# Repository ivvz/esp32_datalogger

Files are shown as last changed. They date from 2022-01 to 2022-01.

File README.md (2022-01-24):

# ESP32 temperature datalogger

ESP32 based type k thermocouple temperature data logger

## Devices

- ESP32 lolin lite board
- OLED Screen SSD1306
- RTC Module DS3231
- Microsd moodule
- Max6675 module
- MT3608 boost dc-dc module
- Two push buttons

## Pinout

### Microsd
- MISO  --- Pin 19
- MOSI --- Pin 23
- SCK --- Pin 18
- CS --- Pin 5
- VCC --- MT3608 VOUT Pin 
- GND --- GND 

### SSD1306 (I2C)
- SCL -- Pin 32
- SDA --- Pin 33
- VCC --- MT3608 VOUT Pin                                                 
- GND --- GND     

### RTC DS3131 (I2C)
- SCL -- Pin 32                                                           
- SDA --- Pin 33 
- VCC --- MT3608 VOUT Pin                                                 
- GND --- GND 

### Thermocouple modules (MAX6675)
- DO (MISO) --- Pin 23                                                    - SCK --- Pin 4                                                          
- CS1 --- Pin 16
- CS2 --- Pin 15  
- CS3 --- Pin 13  
- VCC --- MT3608 VOUT Pin                                                 
- GND --- GND

# Schematics

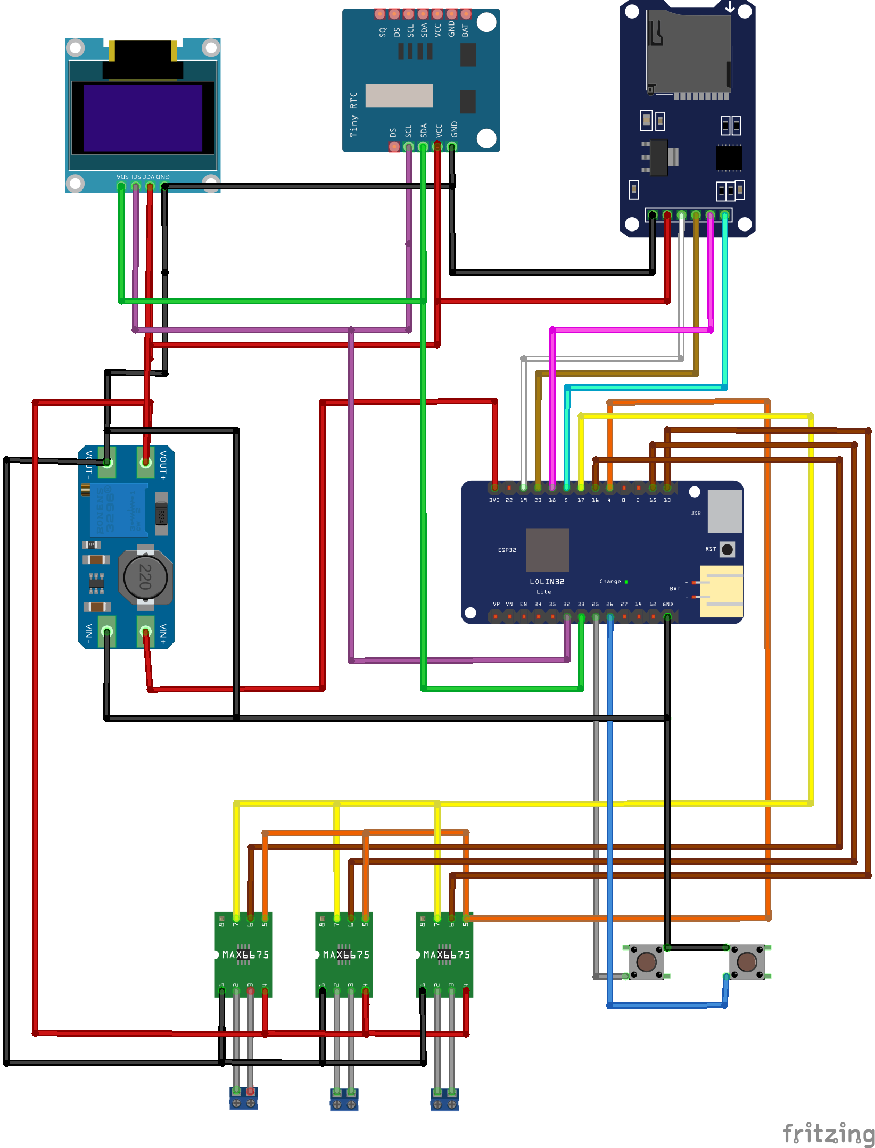
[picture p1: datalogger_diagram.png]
schematics


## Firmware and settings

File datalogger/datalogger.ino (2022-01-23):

#include "FS.h"
#include "SD.h"
#include "max6675.h"
#include <RTClib.h>
#include <SPI.h>
#include <Wire.h>
#include <Adafruit_GFX.h>
#include <Adafruit_SSD1306.h>



int boton_inicio = 25;
int boton_cierre = 26;
int estado_anterior_boton_inicio;
int estado_anterior_boton_final;
unsigned long tiempo_lectura = 10000; // intervalo de lectura general (sin ejecutar funcion de registro de datos)
unsigned long tiempo_sin_registro;
unsigned long tiempoEsperaLog = 0;

int thermoDO = 17;
int thermoCLK = 4;
int thermoCS1 = 16;
int thermoCS2 = 15;
int thermoCS3 = 13;

RTC_DS3231 rtc;     // crea objeto del tipo RTC_DS3231

MAX6675 termopar1(thermoCLK, thermoCS1, thermoDO);
MAX6675 termopar2(thermoCLK, thermoCS2, thermoDO);
MAX6675 termopar3(thermoCLK, thermoCS3, thermoDO);

#define SCREEN_WIDTH 128 // OLED display width, in pixels
#define SCREEN_HEIGHT 64 // OLED display height, in pixels

// Declaration for an SSD1306 display connected to I2C (SDA, SCL pins)
#define OLED_RESET     -1 // Reset pin # (or -1 if sharing Arduino reset pin)
Adafruit_SSD1306 display(SCREEN_WIDTH, SCREEN_HEIGHT, &Wire, OLED_RESET);
 
 
void setup(){
  Wire.begin(33, 32);
  Serial.begin(115200);
  delay(2000);

  //define los botones
  pinMode(boton_inicio, INPUT_PULLUP);
  pinMode(boton_cierre, INPUT_PULLUP);
  digitalWrite(boton_inicio, HIGH);
  digitalWrite(boton_inicio, HIGH);
  estado_anterior_boton_inicio = digitalRead(boton_inicio);
  estado_anterior_boton_final = digitalRead(boton_cierre);
  
  checkOLED();
  checkClock();
  //rtc.adjust(DateTime(__DATE__, __TIME__));  // funcion que permite establecer fecha y horario
             //al momento de la compilacion. Comentar esta linea
  checkSD();
 
}

void loop(){
  String hora;
  unsigned long displayTermoTime;
  unsigned long displayHourTime;
  if(millis() - tiempo_sin_registro >= tiempo_lectura){
     hora = getTime();
     Serial.println(hora + " Termopar 1 = " + String(termopar1.readCelsius()) + " C");
     Serial.println(hora + " Termopar 2 = " + String(termopar2.readCelsius()) + " C");
     Serial.println(hora + " Termopar 3 = " + String(termopar3.readCelsius()) + " C\n");
     showHour(0);
     delay(2000);
     displayHourTime = millis();
     if(millis() - displayHourTime <= 5000){
     displayTermoparData(0);
     displayHourTime = millis();
     }
     tiempo_sin_registro = millis();  
    }

  int estado_actual_boton_inicio = digitalRead(boton_inicio);
  int estado_actual_boton_final = digitalRead(boton_cierre);

  if (estado_actual_boton_inicio == LOW && estado_anterior_boton_inicio == HIGH ) {
      String dataString;
      String hourFile = getNameDate();
      String nombre;
      nombre += "/" + hourFile + ".csv";
      Serial.println("Nombre del archivo: " + nombre);
      Serial.println("Escribiendo datos");
      display.clearDisplay();
      display.setTextSize(2);
      display.setCursor(0,20);            
      display.print("CREANDO");
      display.setTextSize(2);  
      display.setCursor(20,40);            
      display.print("ARCHIVO");
      display.display();
      createFile(nombre);
      delay(5000);
     
     
    while(estado_actual_boton_final == HIGH){
      if(millis() - tiempoEsperaLog >= tiempo_lectura){
      dataString = createString();
      appendTempString(dataString,nombre);
      Serial.println(dataString);
      showHour(1);
      delay(2000);
      displayTermoparData(1);
      tiempoEsperaLog = millis();
      }
      estado_actual_boton_final = digitalRead(boton_cierre);
      }
      Serial.println("cerrando archivo....");
      Serial.println("se cerro el archivo.......\nvolviendo a la lectura");
      display.clearDisplay();
      display.setTextSize(2);
      display.setCursor(0,20);            
      display.print("GUARDANDO");
      display.setTextSize(2);  
      display.setCursor(20,40);            
      display.print("ARCHIVO");
      display.display();
      delay(5000);
  }
 
}



String createString(){
  // crea el string para csv con las temperaturas
    String dataString = "";
    String hora = getTime();
    unsigned long tiempo = millis();
    float lectura1 = termopar1.readCelsius();
    float lectura2 = termopar2.readCelsius();
    float lectura3 = termopar3.readCelsius();
    dataString += hora + ",";
    dataString += String(tiempo);
    dataString += ",";
    dataString += String(lectura1);
    dataString += ",";
    dataString += String(lectura2);
    dataString += ",";
    dataString += String(lectura3) + "\n";

  return dataString;
}


void createFile(String fileName){
  String header = ("hora,tiempo,termopar 1,termopar 2,termopar 3\n");
  writeFile(SD, fileName, header);
}

void appendTempString(String dataString, String fileName){
  appendFile(SD, fileName, dataString);
}

void checkSD(){
    display.clearDisplay();
    display.setTextSize(2);            
    display.setTextColor(WHITE);        
    display.setCursor(2,20);            
    display.println("REVISANDO  MICRO SD!");
    display.display();
    delay(2000);
    display.clearDisplay();
   
    if(!SD.begin(5)){
    Serial.println("Card Mount Failed");
    display.setTextSize(2);            
    display.setTextColor(WHITE);        
    display.setCursor(10,20);            
    display.println(F("FALL0 SD!"));
    display.display();
    delay(10000);
    display.clearDisplay();
    return;
  }else{  
    display.setTextSize(3);            
    display.setTextColor(WHITE);        
    display.setCursor(40,10);            
    display.println("SD");
    display.setCursor(40,40);
    display.println("OK!");
    display.display();
    delay(2000);
    display.clearDisplay();
  }
 
  uint8_t cardType = SD.cardType();

  if(cardType == CARD_NONE){
    Serial.println("NO SE DETECTO UNA TARJETA");
    display.setTextSize(3);            
    display.setTextColor(WHITE);        
    display.setCursor(5,10);            
    display.println("NO SE DETECTO");
    display.setCursor(40,40);
    display.println("SD!");
    display.display();
    delay(2000);
    display.clearDisplay();
    return;
  }
  }

void checkOLED(){
  if(!display.begin(SSD1306_SWITCHCAPVCC, 0x3C)) {
    Serial.println(F("SSD1306 allocation failed"));
    for(;;); // Don't proceed, loop forever
  }
}

void checkClock(){
 if (! rtc.begin()) {       // si falla la inicializacion del modulo
 Serial.println("Modulo RTC no encontrado !");  // muestra mensaje de error
 while (1);         // bucle infinito que detiene ejecucion del programa
 }
}

void displayTermoparData(int isLogging){
     display.clearDisplay();
     if(isLogging == 0){
     display.setTextSize(1);
     display.setTextColor(WHITE);        
     display.setCursor(12,0);            
     display.print("ALMEXA INGENIERIA");
      } else {
     display.setTextSize(1);
     display.setTextColor(WHITE);        
     display.setCursor(5,0);            
     display.print("Registrando Datos");   
      }
     
     display.setTextSize(1);            
     display.setTextColor(WHITE);        
     display.setCursor(0,14);            
     display.print("Tp 1");
     display.setTextSize(2);  
     display.setCursor(30,14);            
     display.print(String(termopar1.readCelsius()) + " C");

     display.setTextSize(1);
     display.setCursor(0,32);            
     display.print("Tp 2");
     display.setTextSize(2);  
     display.setCursor(30,32);            
     display.print(String(termopar2.readCelsius()) + " C");
     display.display();

     display.setTextSize(1);
     display.setCursor(0,50);            
     display.print("Tp 3");
     display.setTextSize(2);  
     display.setCursor(30,50);            
     display.print(String(termopar3.readCelsius()) + " C");
     display.display();
}



void testWatch(){
  DateTime fecha = rtc.now();      // funcion que devuelve fecha y horario en formato
            // DateTime y asigna a variable fecha
 Serial.print(fecha.day());     // funcion que obtiene el dia de la fecha completa
 Serial.print("/");       // caracter barra como separador
 Serial.print(fecha.month());     // funcion que obtiene el mes de la fecha completa
 Serial.print("/");       // caracter barra como separador
 Serial.print(fecha.year());      // funcion que obtiene el año de la fecha completa
 Serial.print(" ");       // caracter espacio en blanco como separador
 Serial.print(fecha.hour());      // funcion que obtiene la hora de la fecha completa
 Serial.print(":");       // caracter dos puntos como separador
 Serial.print(fecha.minute());      // funcion que obtiene los minutos de la fecha completa
 Serial.print(":");       // caracter dos puntos como separador
 Serial.println(fecha.second());    // funcion que obtiene los segundos de la fecha completa
 
 delay(1000);
  }

void showHour(int isLogging){
    display.clearDisplay();
    if(isLogging == 0){
    display.setTextSize(1);
    display.setTextColor(WHITE);        
    display.setCursor(12,0);            
    display.print("ALMEXA INGENIERIA");
    }else {
    display.setTextSize(1);
    display.setTextColor(WHITE);        
    display.setCursor(15,10);            
    display.print("Registrando Datos");
    display.setCursor(12,0);            
    display.print("ALMEXA INGENIERIA");   
    }

  
  DateTime fecha = rtc.now();
  
 
  display.setTextColor(WHITE);        
  display.setTextSize(2);
  display.setCursor(22,22);
  display.print(String(fecha.hour()));
  display.setCursor(42,22);
  display.print(":");
  display.setCursor(52,22);         
  display.print(String(fecha.minute()));
  display.setCursor(73,22);
  display.print(":");    
  display.setCursor(82,22);            
  display.print(String(fecha.second()));

 display.setCursor(10,45); 
 display.print(fecha.day());     // funcion que obtiene el dia de la fecha completa
 display.setCursor(35,45); 
 display.print("/");       // caracter barra como separador
 display.setCursor(45,45); 
 display.print(fecha.month());     // funcion que obtiene el mes de la fecha completa
 display.setCursor(55,45); 
 display.print("/");       // caracter barra como separador
 display.setCursor(70,45); 
 display.print(fecha.year());      // funcion que obtiene el año de la fecha completa
 display.display();
 delay(1000);
  
}


void errorCreatingFile(){
    display.clearDisplay();
    display.setTextSize(2);            
    display.setTextColor(WHITE);        
    display.setCursor(0,10);            
    display.println("ERROR AL ");
    display.setCursor(10,30);
    display.println("CREAR");
    display.setCursor(2,50);
    display.println("ARCHIVO!");
    display.display();
    delay(2000);
}

void errorAbrirArchivo(){
    display.clearDisplay();
    display.setTextSize(2);            
    display.setTextColor(WHITE);        
    display.setCursor(5,10);            
    display.println("ERROR AL ");
    display.setCursor(10,30);
    display.println("ABRIR");
    display.setCursor(2,50);
    display.println("ARCHIVO!");
    display.display();
    delay(2000);
}

String getTime(){
  DateTime fecha = rtc.now();
  String hora;
  hora = String(fecha.hour()) + ":" + String(fecha.minute()) + ":" + String(fecha.second());
  return hora;
}


String getNameDate(){
  DateTime fecha = rtc.now();
  String date;
  date = String(fecha.day()) + "-" + String(fecha.month())+ "-" + String(fecha.hour()) + String(fecha.minute());
  return date;
}























void listDir(fs::FS &fs, const char * dirname, uint8_t levels){
  Serial.printf("Listing directory: %s\n", dirname);

  File root = fs.open(dirname);
  if(!root){
    Serial.println("Failed to open directory");
    return;
  }
  if(!root.isDirectory()){
    Serial.println("Not a directory");
    return;
  }

  File file = root.openNextFile();
  while(file){
    if(file.isDirectory()){
      Serial.print("  DIR : ");
      Serial.println(file.name());
      if(levels){
        listDir(fs, file.name(), levels -1);
      }
    } else {
      Serial.print("  FILE: ");
      Serial.print(file.name());
      Serial.print("  SIZE: ");
      Serial.println(file.size());
    }
    file = root.openNextFile();
  }
}

void createDir(fs::FS &fs, const char * path){
  Serial.printf("Creating Dir: %s\n", path);
  if(fs.mkdir(path)){
    Serial.println("Dir created");
  } else {
    Serial.println("mkdir failed");
  }
}

void removeDir(fs::FS &fs, const char * path){
  Serial.printf("Removing Dir: %s\n", path);
  if(fs.rmdir(path)){
    Serial.println("Dir removed");
  } else {
    Serial.println("rmdir failed");
  }
}

void readFile(fs::FS &fs, const char * path){
  Serial.printf("Reading file: %s\n", path);

  File file = fs.open(path);
  if(!file){
    Serial.println("Failed to open file for reading");
    

    return;
  }

  Serial.print("Read from file: ");
  while(file.available()){
    Serial.write(file.read());
  }
  file.close();
}

void writeFile(fs::FS &fs, String path, String message){
  Serial.printf("Writing file: %s\n", path);

  File file = fs.open(path, FILE_WRITE);
  if(!file){
    Serial.println("Failed to open file for writing");
    errorCreatingFile();
    return;
  }
  if(file.print(message)){
    Serial.println("File written");
  } else {
    Serial.println("Write failed");
  }
  file.close();
}

void appendFile(fs::FS &fs, String path, String message){
  Serial.printf("Appending to file: %s\n", path);

  File file = fs.open(path, FILE_APPEND);
  if(!file){
    Serial.println("Failed to open file for appending");
    errorAbrirArchivo();
    return;
  }
  if(file.print(message)){
      Serial.println("Message appended");
  } else {
    Serial.println("Append failed");
  }
  file.close();
}

void renameFile(fs::FS &fs, const char * path1, const char * path2){
  Serial.printf("Renaming file %s to %s\n", path1, path2);
  if (fs.rename(path1, path2)) {
    Serial.println("File renamed");
  } else {
    Serial.println("Rename failed");
  }
}

void deleteFile(fs::FS &fs, const char * path){
  Serial.printf("Deleting file: %s\n", path);
  if(fs.remove(path)){
    Serial.println("File deleted");
  } else {
    Serial.println("Delete failed");
  }
}

void testFileIO(fs::FS &fs, const char * path){
  File file = fs.open(path);
  static uint8_t buf[512];
  size_t len = 0;
  uint32_t start = millis();
  uint32_t end = start;
  if(file){
    len = file.size();
    size_t flen = len;
    start = millis();
    while(len){
      size_t toRead = len;
      if(toRead > 512){
        toRead = 512;
      }
      file.read(buf, toRead);
      len -= toRead;
    }
    end = millis() - start;
    Serial.printf("%u bytes read for %u ms\n", flen, end);
    file.close();
  } else {
    Serial.println("Failed to open file for reading");
  }


  file = fs.open(path, FILE_WRITE);
  if(!file){
    Serial.println("Failed to open file for writing");
    return;
  }

  size_t i;
  start = millis();
  for(i=0; i<2048; i++){
    file.write(buf, 512);
  }
  end = millis() - start;
  Serial.printf("%u bytes written for %u ms\n", 2048 * 512, end);
  file.close();
}

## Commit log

2022-01-09 la sd funciona pero todavia tengo todo el monton de codigo de abajo XD
2022-01-09 funciona el temopar y la sd. no es posible conetar el termopar al mismo puerto spi que la tarjeta.
2022-01-09 agregue una pantalla y muestra la temperatura de 3 termopares aunque solo uno este conectado gg
2022-01-09 ya se registran los datos en la memoria en el formato chido
2022-01-10 se agregaron los botones para iniciar y finalizar el registro de datos. La pantalla muestra mmenjsajes de inicio y de termino de registro y al parecer todo funciona muy bonito. Soy feliz :)
2022-01-10 Que triste no funcionaba y me emocione, pero ahora parece que ya funciona todo..... vamoaprobar. Se corrigio la forma en la que se creaba el nombre del archivo.
    [datalogger.ino]
2022-01-10 se arreglo el problema de como se mosttraban los datos durante el registro
    [datalogger.ino]
2022-01-16 ya funciona el etc con la tarjeta
2022-01-16 ya funciona el reloj y se muestra la hora y fecha en la pantalla de sin registro de datos
2022-01-16 se agregaron mensajes de error al crear y abrir archivos
    [datalogger.ino]
2022-01-16 se agregaron mensajes de error al crear y abrir archivos x 2
    [datalogger.ino]
2022-01-16 ya funciona el reloj y muestra diversos mendajes y asi. falta agregar la hora al csv
2022-01-16 se cambio el codigo para que el archivo incluyera la hora en los datos, ademas, ek nombre del archivo quedo como: dia-mes-hora". Falta quitar algunos delays, pero todo funciona bien.
2022-01-19 cambios en la ejecucion del programa. El inicio y registro de datos se efectua cuando se muestran las temperaturas en la pantalla
2022-01-23 Se corrigio el error de la falla del registro de datos (solo guardaba la cabecera del csv). Se agrega el diagrama de conecciones
    [datalogger Sketch.fzz]
2022-01-24 nuevo esquema
    [datalogger Sketch.fzz]
